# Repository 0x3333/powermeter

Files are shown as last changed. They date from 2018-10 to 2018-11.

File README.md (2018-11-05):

# This project has _not been finished_
# Software is still incomplete
# Looks like I was able to create a sensor in
# ESPurna firmware to handle 3 PZEM004T devices
# So this project is _halted_ until it is eventually needed

[Sensor commit in ESPurna](https://github.com/0x3333/espurna/commit/9d440fd216d5b156dd9e168d6f8793874f21e5dd)

# Power Meter

This project reads multiple PZEM004T readers in the same UART(Support for 6 devices), using Multi-drop TX. It reads all devices constantly and when asked, will send the last reading, synchronously. It uses UART to read the devices and I2C to responde to a master node. I2C Address is `0x33`.

The default implementation is using an Arduino Pro Mini clone(Funduino), the software is using [Simba Framework](https://github.com/eerimoq/simba/).

Folder `pcb` contains the schematics and my PCB version of the reader.

This project support 2 hacks in the PZEM004T:

1. Power direction, allows the reader to know the direction of the power, used in setups with solar panels, etc.
2. Remote reset, allows the reader to reset the counter remotely, without user interaction(Reset all simultaneously, not possible to reset individualy).

These hacks, will be documented here later, the PCB includes 3 mini pcbs that will hold the optocouplers need to isolate the high voltage.

## Info

* The `TX#_EN` pins are used to disable a device `TX` line, so we can set the addresses without user interaction. We force `TX#_EN` `High` on all devices except the one we want to set the address, and then send the set address command. There is a jumper to enable/disable this in case of failure to work.
* `DC_DC` component is a 5V->3.3V converter, I'm using these: [Step-Down Power Supply Buck Module AMS1117](https://www.aliexpress.com/item/10Pcs-5V-To-3-3V-DC-DC-Step-Down-Power-Supply-Buck-Module-AMS1117-800MA/32838774398.html)

## PCB

[Schematic](https://github.com/0x3333/powermeter/raw/master/pcb/schematic.pdf)

[PCB](https://github.com/0x3333/powermeter/raw/master/pcb/pcb.pdf)

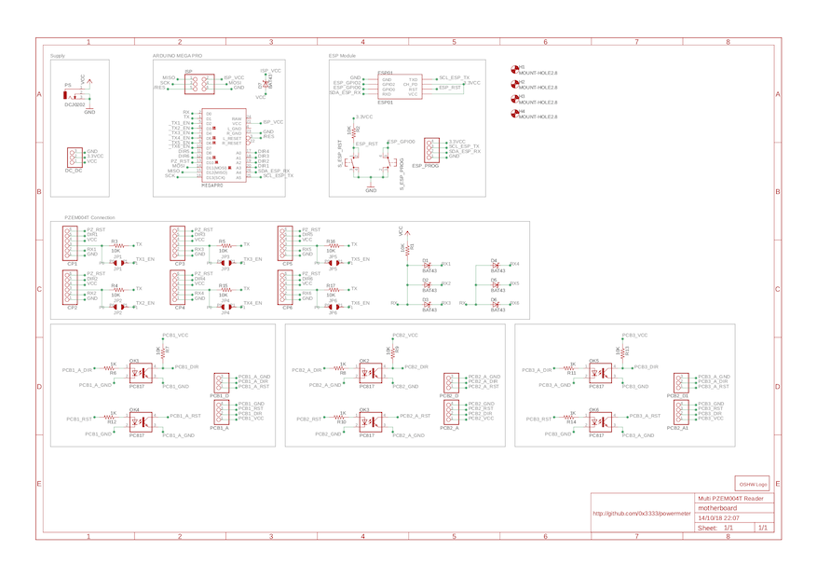
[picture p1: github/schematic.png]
Schematic


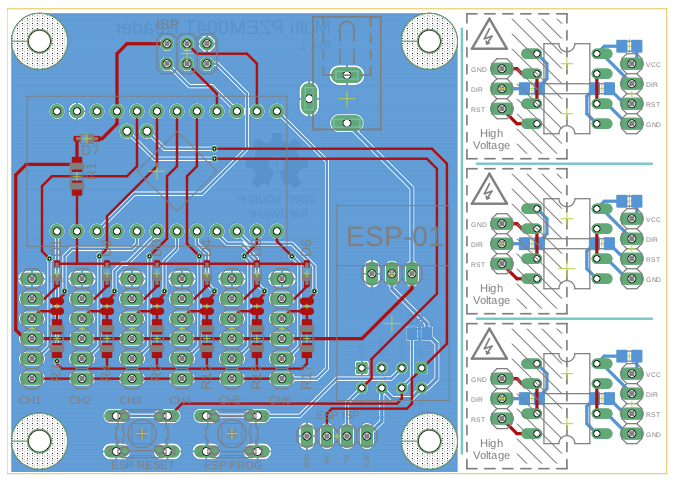
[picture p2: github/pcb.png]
PCB


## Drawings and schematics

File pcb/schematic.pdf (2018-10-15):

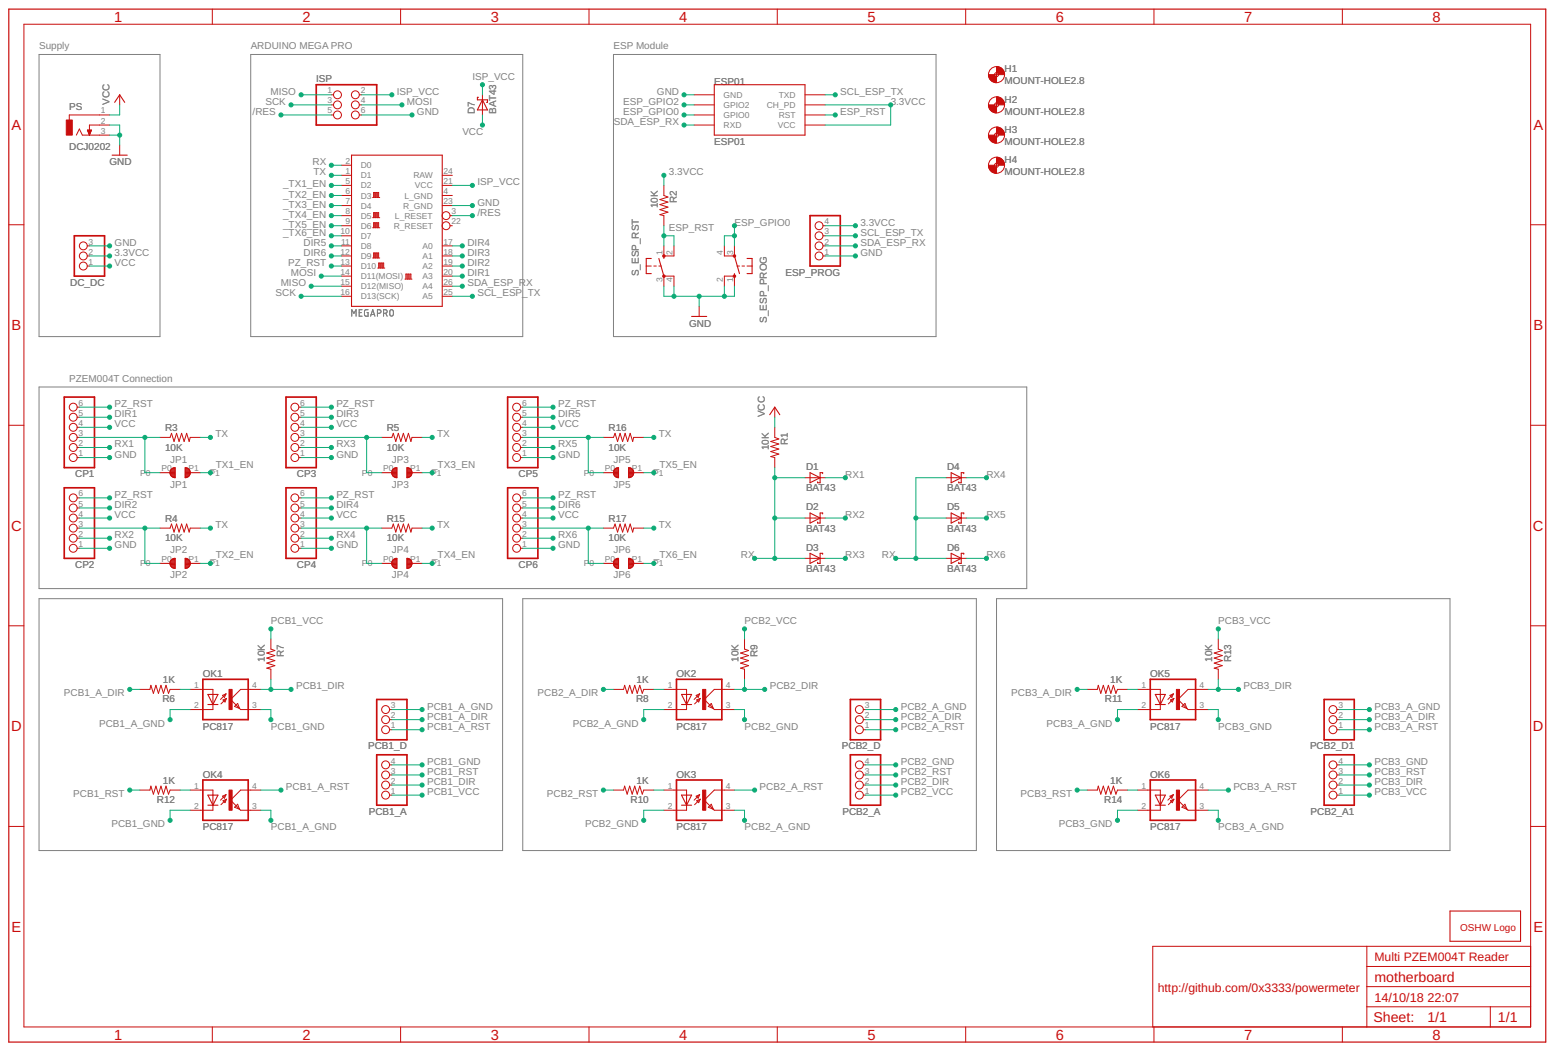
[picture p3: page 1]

MOUNT-HOLE2.8 MOUNT-HOLE2.8

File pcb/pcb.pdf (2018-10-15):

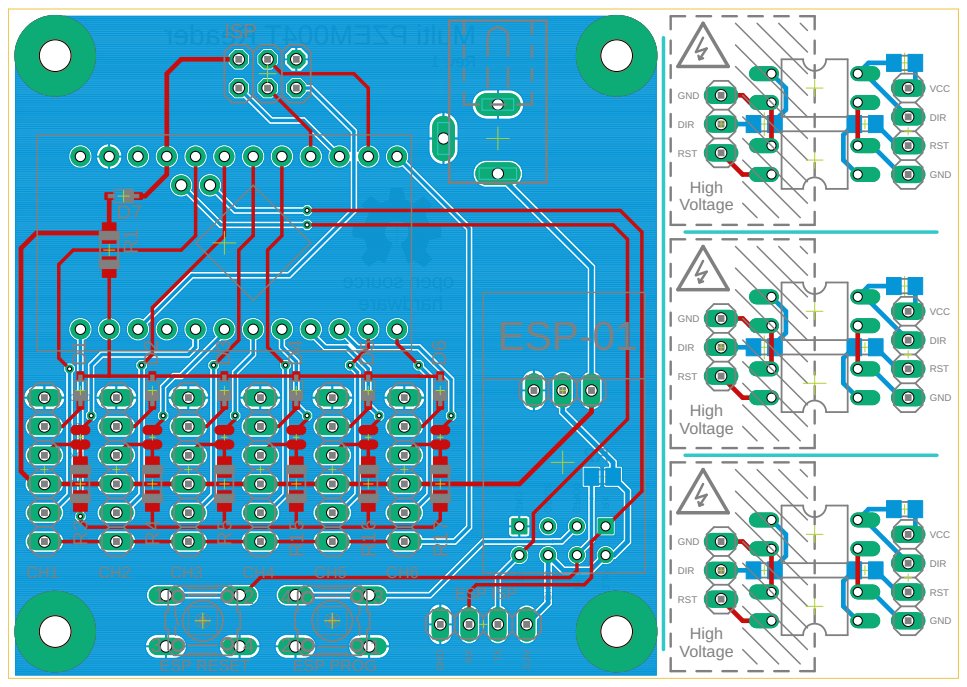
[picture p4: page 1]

r edae R T400 MEZPitl u M 2 R ecr uos nepo er a wdr ah GND 3.3V RST CH/PDTX GPIO2 GPIO0 RX DNG XTXRCCV RI D TSR 1. ve R RST DIR GND RST DIR GND RST DIR GND ESP ISP GNDRXTX 3.3V CH1 CH2 CH3 CH4 CH5 CH6 GND RST DIR VCC GND RST DIR VCC GND RST DIR VCC High Voltage High Voltage High Voltage ESP-01 1 2 3 4 2 1 4 3 ESP RESET ESP PROG ISP D1 D2 D3 R1 R3 R4 R5 D7 D4 D5 D6 R15 R16 R17

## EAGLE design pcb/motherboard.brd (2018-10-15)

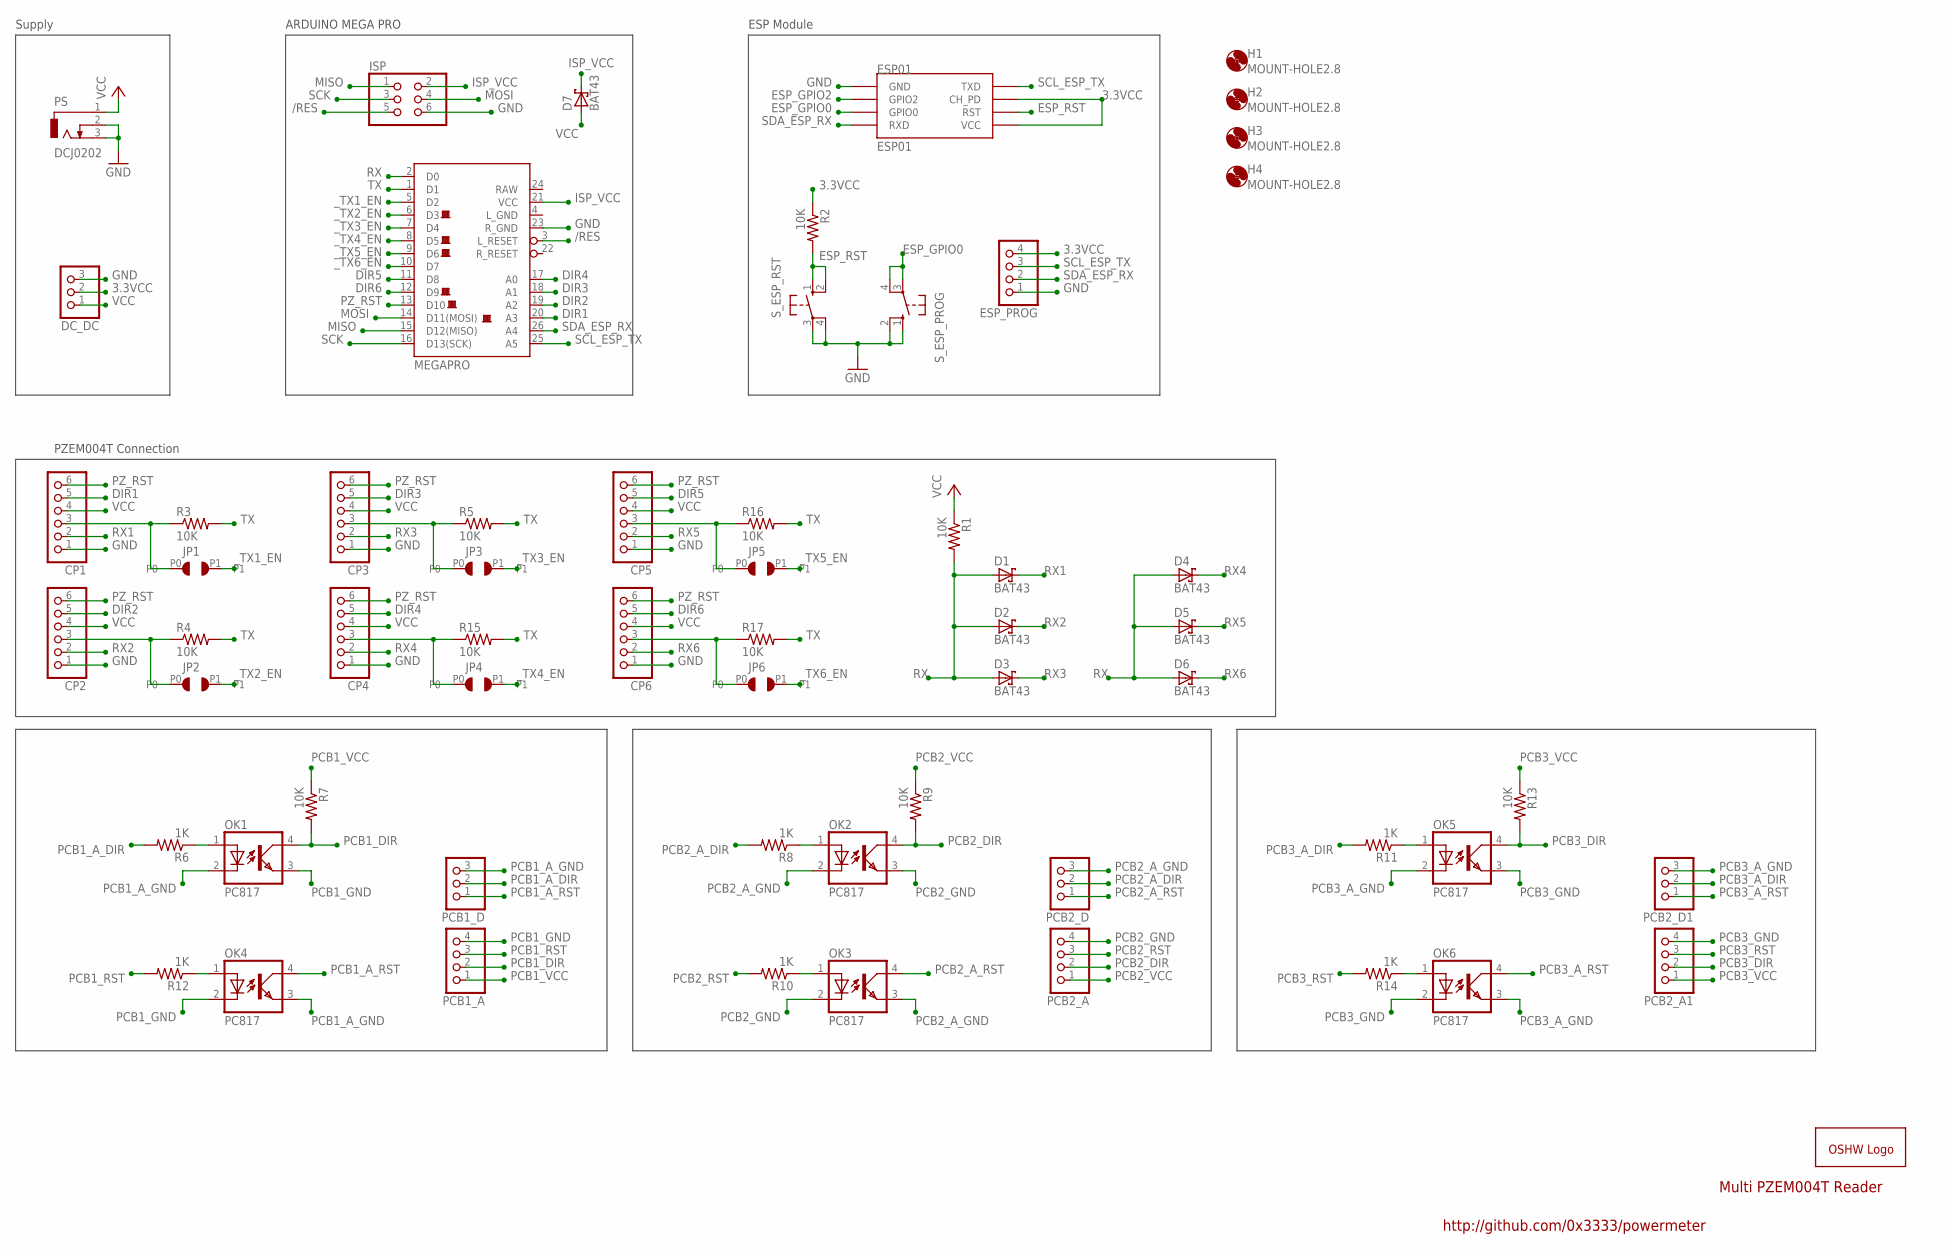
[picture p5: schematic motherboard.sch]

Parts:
CP1, CP2, CP3, CP4, CP5, CP6: PINHD-1X6; 1X06
D1, D2, D3, D4, D5, D6, D7: BAT43; SOD323_ST
DC_DC: PINHD-1X3; 1X03
ESP01: ESP01
ESP_PROG: PINHD-1X4; 1X04
GOLD_ORB_SM1: OSHWLOGOLOGO8MM; OSHW_8MM
H1, H2, H3, H4: MOUNT-HOLE2.8; 2,8
ISP: PINHD-2X3; 2X03
JP1, JP2, JP3, JP4, JP5, JP6: SMD_JUMPER
MEGAPRO: ARDUINO_PRO_MINI
OK1, OK2, OK3, OK4, OK5, OK6: PC817; DIL04
PCB1_A, PCB2_A, PCB2_A1: PINHD-1X4; 1X04
PCB1_D, PCB2_D, PCB2_D1: PINHD-1X3; 1X03
PS: DCJ0202
R1, R3, R4, R5, R15, R16, R17: 10K; R1206W
R2, R7, R9, R13: 10K; R0805
R6, R8, R10, R11, R12, R14: 1K; R0805
S_ESP_PROG: 10-XX; B3F-10XX
S_ESP_RST: 10-XX; B3F-10XX

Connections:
3.3VCC: DC_DC.2, ESP01.CH_PD, ESP01.VCC, ESP_PROG.4, R2.1
/RES: ISP.5, MEGAPRO.3 (L_RESET)
DIR1: CP1.5, MEGAPRO.20 (A3)
DIR2: CP2.5, MEGAPRO.19 (A2)
DIR3: CP3.5, MEGAPRO.18 (A1)
DIR4: CP4.5, MEGAPRO.17 (A0)
DIR5: CP5.5, MEGAPRO.11 (D8)
DIR6: CP6.5, MEGAPRO.12 (D9)
ESP_GPIO0: ESP01.GPIO0, S_ESP_PROG.3, S_ESP_PROG.4 (P1)
ESP_GPIO2: ESP01.GPIO2
ESP_RST: ESP01.RST, R2.2, S_ESP_RST.1 (S), S_ESP_RST.2 (S1)
GND: CP1.1, CP2.1, CP3.1, CP4.1, CP5.1, CP6.1, DC_DC.3, ESP01.GND, ESP_PROG.1, ISP.6, MEGAPRO.23 (R_GND), PS.2, PS.3, S_ESP_PROG.1 (S), S_ESP_PROG.2 (S1), S_ESP_RST.3, S_ESP_RST.4 (P1)
ISP_VCC: D7.C, ISP.2, MEGAPRO.21 (VCC)
MISO: ISP.1, MEGAPRO.15 (D12(MISO))
MOSI: ISP.4, MEGAPRO.14 (D11(MOSI))
unnamed: CP1.3, JP1.P0, R3.1
unnamed: CP2.3, JP2.P0, R4.1
unnamed: OK1.1 (A), R6.1
unnamed: CP3.3, JP3.P0, R5.1
unnamed: OK2.1 (A), R8.1
unnamed: OK3.1 (A), R10.1
unnamed: OK5.1 (A), R11.1
unnamed: OK6.1 (A), R14.1
unnamed: CP4.3, JP4.P0, R15.1
unnamed: CP5.3, JP5.P0, R16.1
unnamed: CP6.3, JP6.P0, R17.1
unnamed: OK4.1 (A), R12.1
PCB1_A_DIR: PCB1_D.2, R6.2
PCB1_A_GND: OK1.2 (C), OK4.3 (EMIT), PCB1_D.3
PCB1_A_RST: OK4.4 (COL), PCB1_D.1
PCB1_DIR: OK1.4 (COL), PCB1_A.2, R7.2
PCB1_GND: OK1.3 (EMIT), OK4.2 (C), PCB1_A.4
PCB1_RST: PCB1_A.3, R12.2
PCB1_VCC: PCB1_A.1, R7.1
PCB2_A_DIR: PCB2_D.2, R8.2
PCB2_A_GND: OK2.2 (C), OK3.3 (EMIT), PCB2_D.3
PCB2_A_RST: OK3.4 (COL), PCB2_D.1
PCB2_DIR: OK2.4 (COL), PCB2_A.2, R9.2
PCB2_GND: OK2.3 (EMIT), OK3.2 (C), PCB2_A.4
PCB2_RST: PCB2_A.3, R10.2
PCB2_VCC: PCB2_A.1, R9.1
PCB3_A_DIR: PCB2_D1.2, R11.2
PCB3_A_GND: OK5.2 (C), OK6.3 (EMIT), PCB2_D1.3
PCB3_A_RST: OK6.4 (COL), PCB2_D1.1
PCB3_DIR: OK5.4 (COL), PCB2_A1.2, R13.2
PCB3_GND: OK5.3 (EMIT), OK6.2 (C), PCB2_A1.4
PCB3_RST: PCB2_A1.3, R14.2
PCB3_VCC: PCB2_A1.1, R13.1
PZ_RST: CP1.6, CP2.6, CP3.6, CP4.6, CP5.6, CP6.6, MEGAPRO.13 (D10)
RX: D1.A, D2.A, D3.A, D4.A, D5.A, D6.A, MEGAPRO.2 (D0), R1.2
RX1: CP1.2, D1.C
RX2: CP2.2, D2.C
RX3: CP3.2, D3.C
RX4: CP4.2, D4.C
RX5: CP5.2, D5.C
RX6: CP6.2, D6.C
SCK: ISP.3, MEGAPRO.16 (D13(SCK))
SCL_ESP_TX: ESP01.TX (TXD), ESP_PROG.3, MEGAPRO.25 (A5)
SDA_ESP_RX: ESP01.RX (RXD), ESP_PROG.2, MEGAPRO.26 (A4)
TX: MEGAPRO.1 (D1), R3.2, R4.2, R5.2, R15.2, R16.2, R17.2
VCC: CP1.4, CP2.4, CP3.4, CP4.4, CP5.4, CP6.4, D7.A, DC_DC.1, PS.1, R1.1
_TX1_EN: JP1.P1, MEGAPRO.5 (D2)
_TX2_EN: JP2.P1, MEGAPRO.6 (D3)
_TX3_EN: JP3.P1, MEGAPRO.7 (D4)
_TX4_EN: JP4.P1, MEGAPRO.8 (D5)
_TX5_EN: JP5.P1, MEGAPRO.9 (D6)
_TX6_EN: JP6.P1, MEGAPRO.10 (D7)

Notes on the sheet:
ESP Module
Supply
PZEM004T Connection
ARDUINO MEGA PRO
Multi PZEM004T Reader
http://github.com/0x3333/powermeter

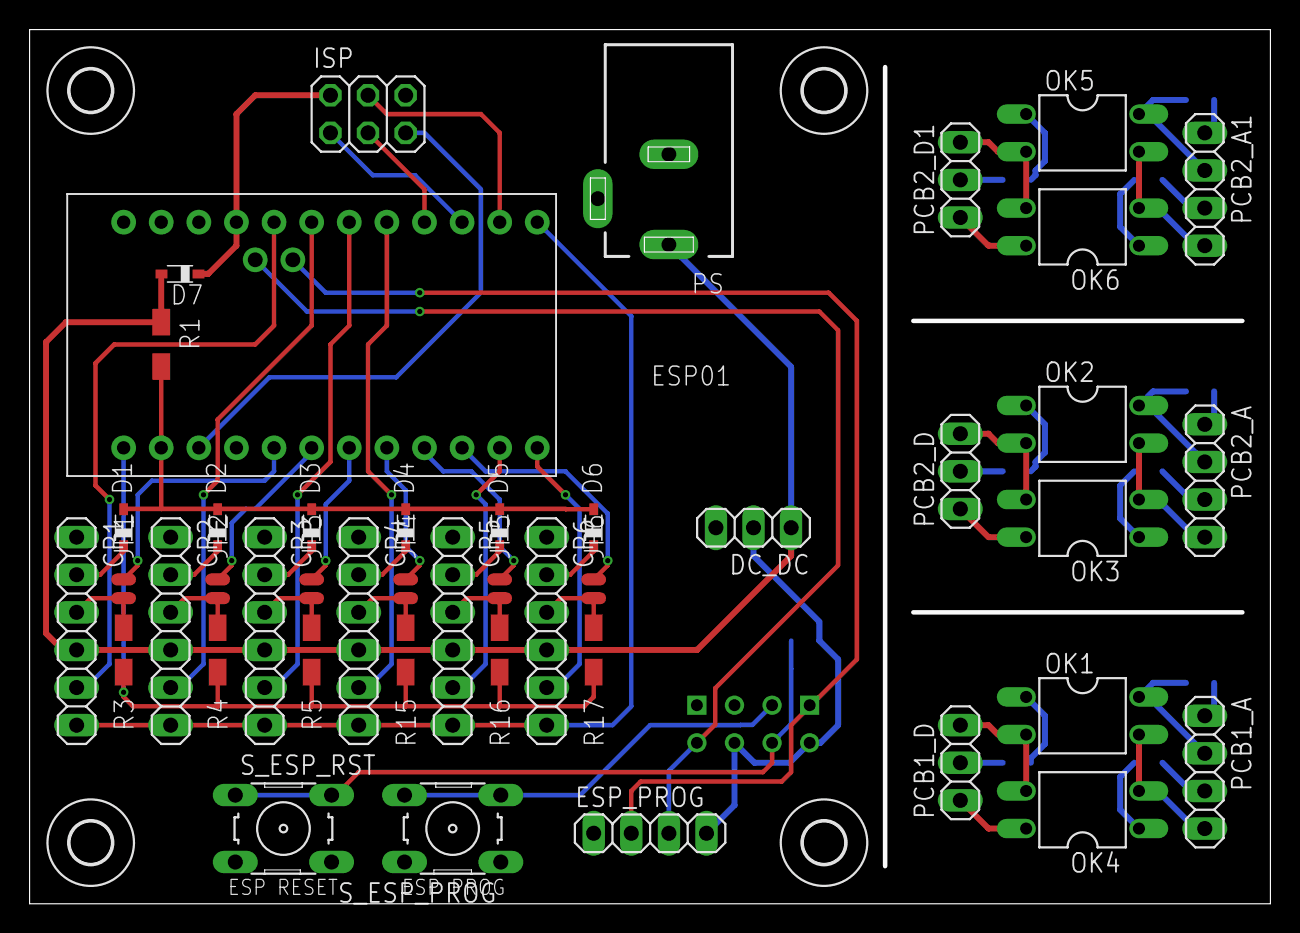
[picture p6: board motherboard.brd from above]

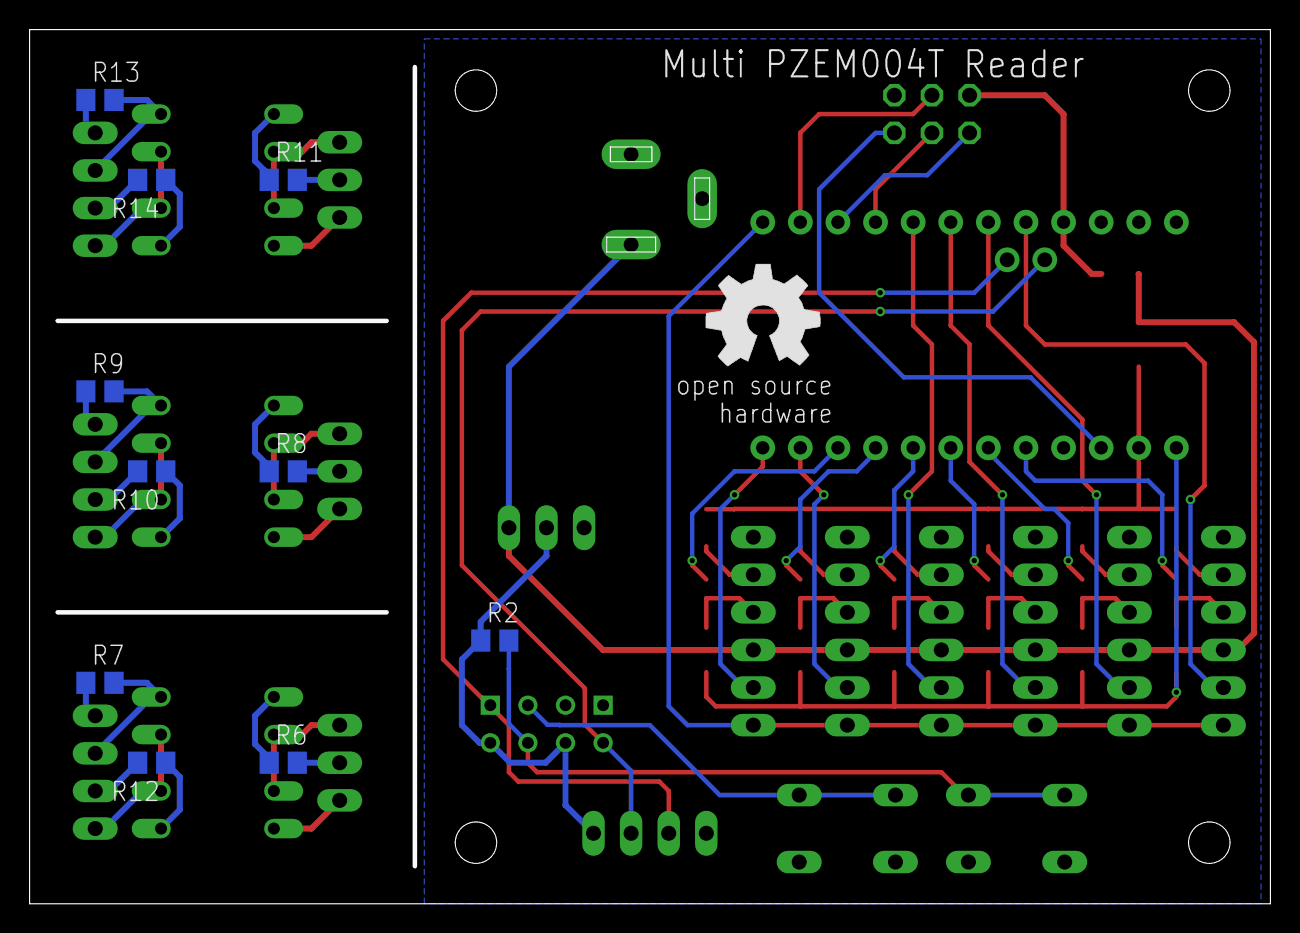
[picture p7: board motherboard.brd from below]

Board: 2 copper layers, 83.8 x 59.0 mm, 61 parts (11 on the bottom side), 66 nets.

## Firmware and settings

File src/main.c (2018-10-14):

// ------------------------------------------------------------------------
#include "simba.h"
//
#include "main.h"
#include "device.h"
#include "i2c.h"

// ------------------------------------------------------------------------
static struct pin_driver_t heartbeat_led;

static void pz_setup()
{
	sys_start();

	pin_init(&heartbeat_led, &pin_led_dev, PIN_OUTPUT);
	pin_write(&heartbeat_led, 0);
}

// Main Thread Entrypoint
int main()
{
	// Setup Hardware
	pz_setup();
	pz_device_setup();
	pz_i2c_setup();

	// Start Read Devices Thread
	pz_device_start();

	// Start I2C Thread
	pz_i2c_start();

	while (1)
	{
		pin_write(&heartbeat_led, 1);
		thrd_sleep_ms(250);
		pin_write(&heartbeat_led, 0);
		thrd_sleep_ms(250);
	}

	return (0);
}

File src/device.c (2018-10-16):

// ------------------------------------------------------------------------
#include "simba.h"
//
#include "main.h"
#include "device.h"

// ------------------------------------------------------------------------
static struct uart_driver_t uart;
static struct pin_driver_t tx_en[6];
static struct pin_driver_t dir[6];
static char buf[16];

// ------------------------------------------------------------------------
static void set_tx_en(uint8_t dev)
{
    for (uint8_t i = 0; i < MAX_DEVICES; i++)
    {
        pin_set_mode(&tx_en[i], (i == dev) ? PIN_INPUT : PIN_OUTPUT);
        pin_write(&tx_en[i], (i == dev) ? 0 : 1);
    }
}

static void read_device(uint8_t dev, struct read *reading)
{
    set_tx_en(dev);
}

// Thread Stack
static THRD_STACK(pz_device_handler_stack, 256);

// Thread Entrypoint
static void *pz_device_handler(void *arg_p)
{
    while (1)
    {
        for (uint8_t dev = 0; dev < MAX_DEVICES; dev++)
        {
            rwlock_writer_take(&readings_lock);
            read_device(dev, &readings[dev]);

            rwlock_writer_give(&readings_lock);
        }
    }

    return NULL;
}

void pz_device_setup()
{
    uart_init(&uart, &uart_device[0], 9600, &buf, sizeof(buf));

    // TX Enable
    pin_init(&tx_en[0], &pin_d2_dev, PIN_INPUT);
    pin_init(&tx_en[1], &pin_d3_dev, PIN_INPUT);
    pin_init(&tx_en[2], &pin_d4_dev, PIN_INPUT);
    pin_init(&tx_en[3], &pin_d5_dev, PIN_INPUT);
    pin_init(&tx_en[4], &pin_d6_dev, PIN_INPUT);
    pin_init(&tx_en[5], &pin_d7_dev, PIN_INPUT);

    // Direction
    pin_init(&dir[0], &pin_a3_dev, PIN_INPUT);
    pin_init(&dir[1], &pin_a2_dev, PIN_INPUT);
    pin_init(&dir[2], &pin_a1_dev, PIN_INPUT);
    pin_init(&dir[3], &pin_a0_dev, PIN_INPUT);
    pin_init(&dir[4], &pin_d8_dev, PIN_INPUT);
    pin_init(&dir[5], &pin_d9_dev, PIN_INPUT);
}

void pz_device_start()
{
    thrd_spawn(&pz_device_handler, NULL, 0, pz_device_handler_stack, sizeof(pz_device_handler_stack));
}

// static uint8_t crc(uint8_t *data, uint8_t size)
// {
//     uint16_t sum = 0;
//     for (uint8_t i = 0; i < size; i++)
//     {
//         sum += *data++;
//     }
//     return (uint8_t)(sum & 0xFF);
// }

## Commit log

2018-10-14 Initial implementation. First PCB revision.
    [motherboard.brd, motherboard.sch]
2018-10-15 Modified to support 6 devices.
    [motherboard.brd, motherboard.sch]
2018-10-15 Added Schematic image and links.
2018-10-15 Added PCB files.
2018-10-15 Updated PCB/Schematic.
    [motherboard.brd, motherboard.sch]
